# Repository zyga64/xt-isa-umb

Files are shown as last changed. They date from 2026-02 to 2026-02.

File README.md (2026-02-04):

### Simple UMB memory expansion for IBM PC (XT) and clones.

With this card, you can add 128 kB of continuous UMB memory in the D0000 - EFFFF area, or only 64 kB in the D0000 - DFFFF or E0000 - EFFFF areas. 

* Original schematic diagram was drawn by Ruud Baltissen (VCF forum thread): https://forum.vcfed.org/index.php?threads/loading-dos-high-on-a-xt.32320/
* The idea for the printed circuit board layout borrowed from Adrian Black: https://github.com/misterblack1/isa-ram-expansion
* 8 bit ISA footprint from Sergey Kiselev: https://github.com/skiselev/my_kicad_library

Diagram/PCB drawn by me in KiCad 9.0, the only minor change from Ruud's schematic is the addition of a 74LS245 buffer for the data bus (as done by Adrian and in the Lo-tech 1MB RAM Board https://www.lo-tech.co.uk/wiki/Lo-tech_1MB_RAM_Board).
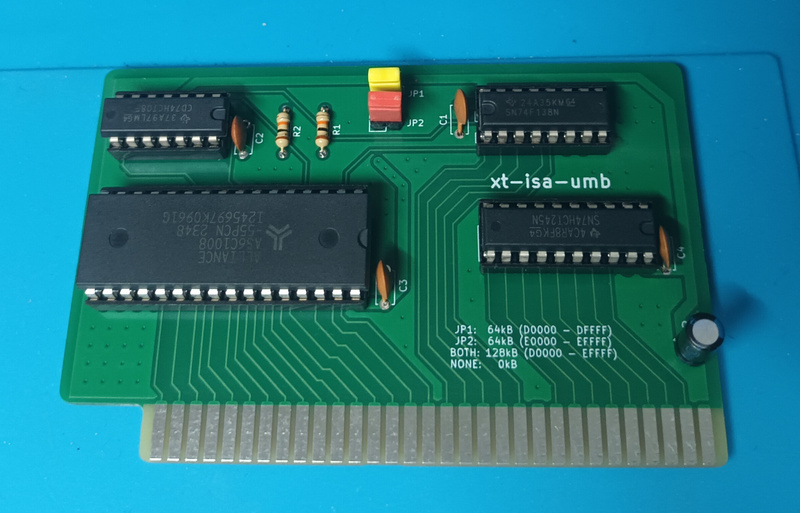
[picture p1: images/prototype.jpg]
picture of working prototype


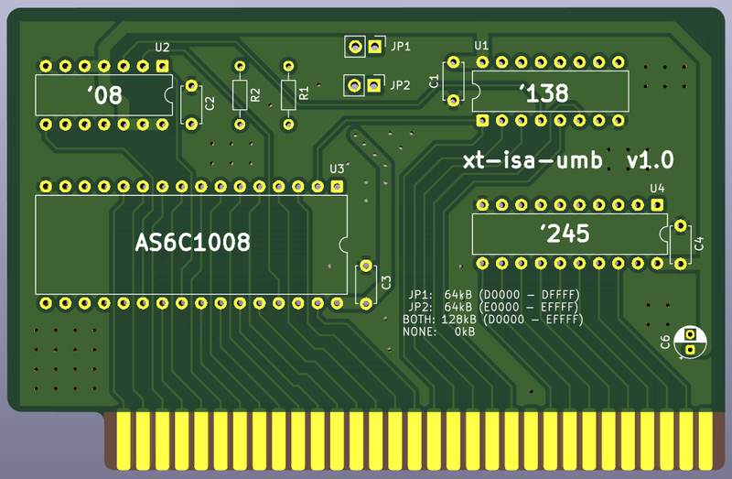
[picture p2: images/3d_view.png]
3d view of PCB


## Bill Of Materials

Reference      | Quantity    | Value                    
---------------|-------------|--------------------------
U1             | 1           | 74HCT138                  
U2             | 1           | 74HCT08                   
U3             | 1           | AS6C1008 (or another compatible 128k x 8bit SRAM)
U4             | 1           | 74HCT245                  
C6             | 1           | 47uF /16V                 
C1, C2, C3, C4 | 4           | 100nF                     
JP1, JP2       | 2           | 1x02 male through-hole pin-header 2.54mm
R1, R2         | 2           | 15k / 0.125W   (pull-up resistors - 10k will also be fine)

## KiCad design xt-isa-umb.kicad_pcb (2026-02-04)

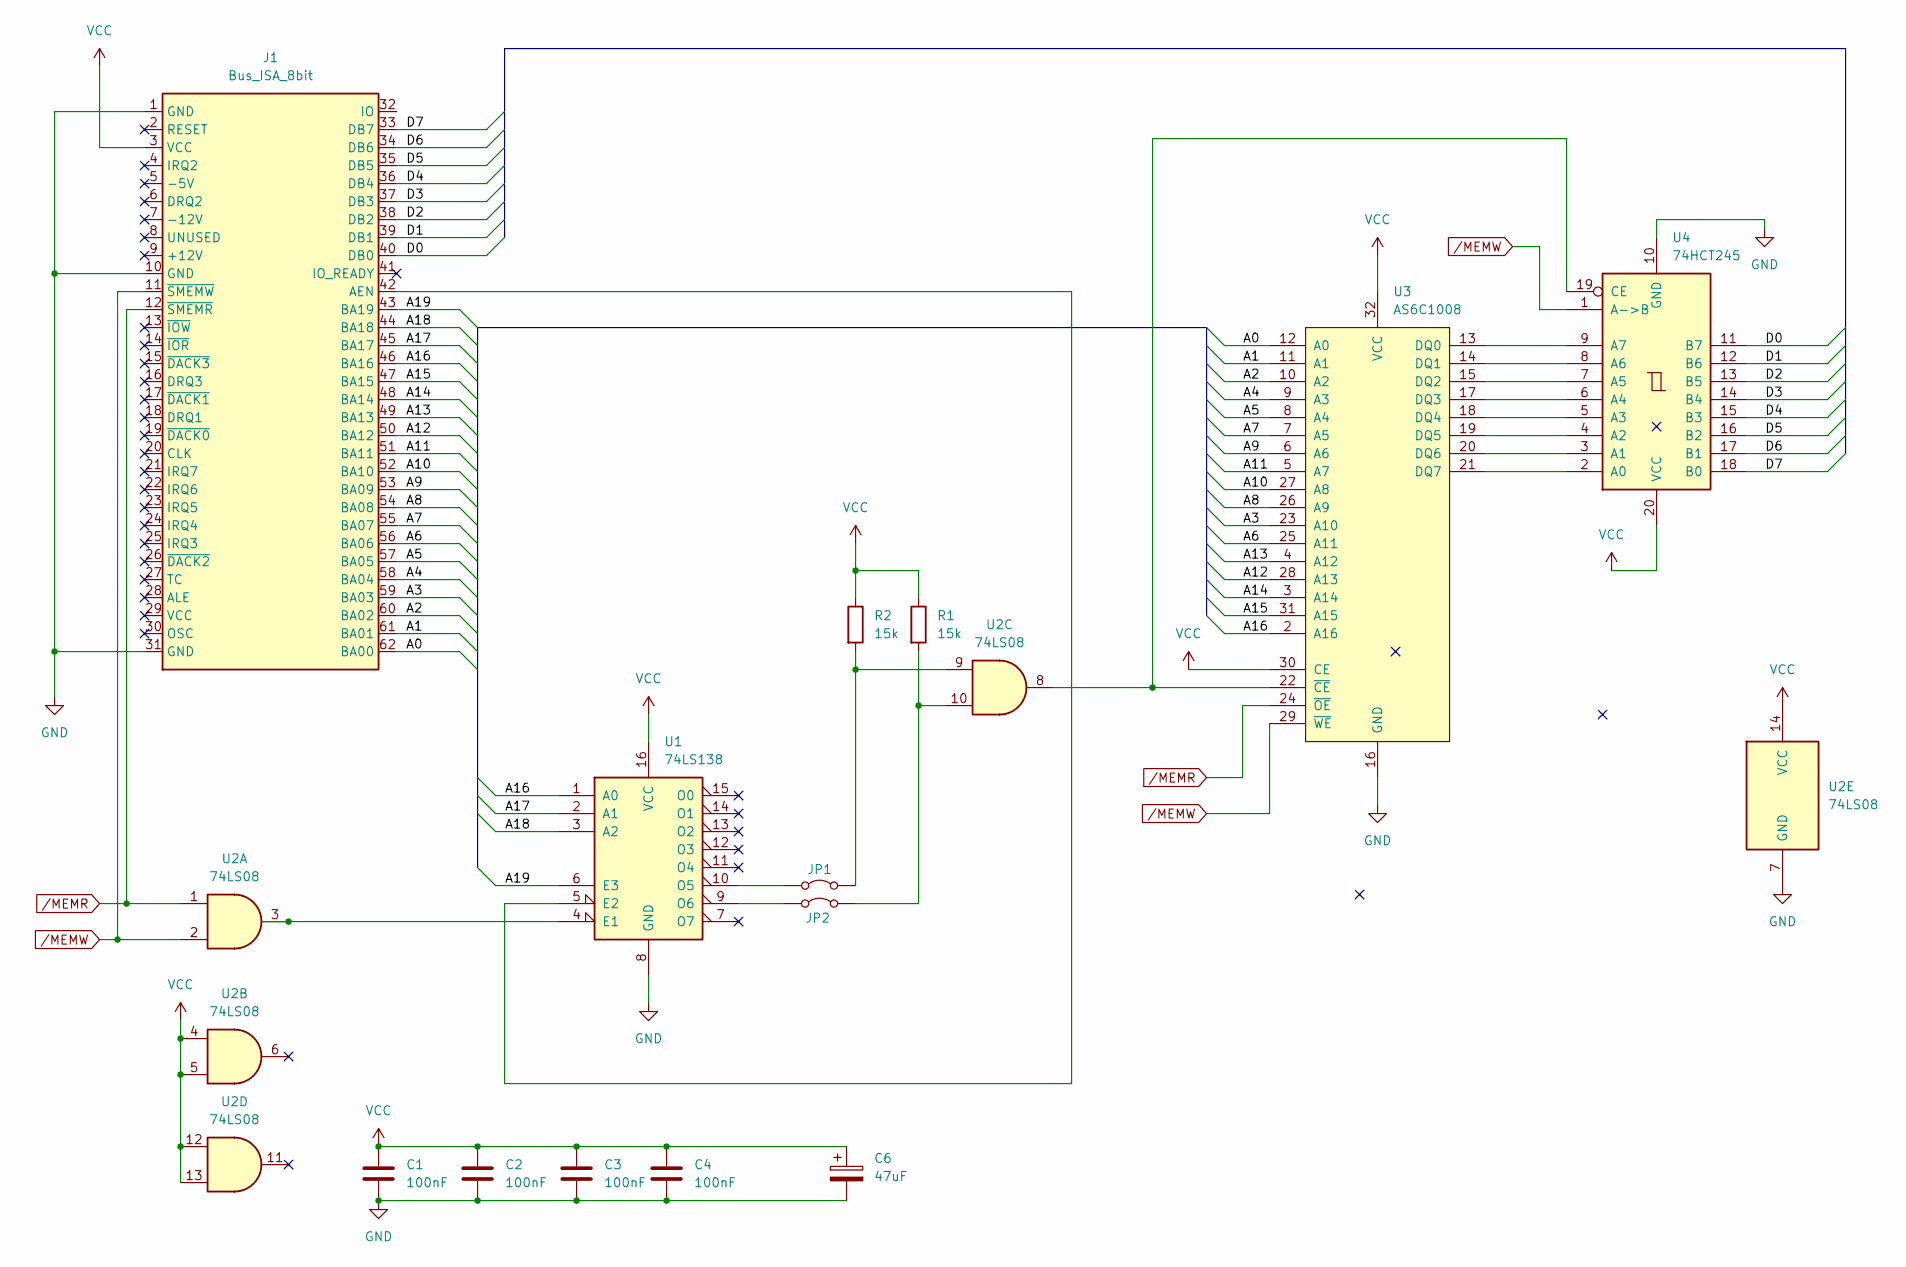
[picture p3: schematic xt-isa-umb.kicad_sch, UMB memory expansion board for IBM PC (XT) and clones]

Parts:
C1, C2, C3, C4: 100nF; C_Disc_D4.7mm_W2.5mm_P5.00mm
C6: 47uF; CP_Radial_D4.0mm_P2.00mm
J1: Bus_ISA_8bit; Conn_Edge_PCB_ISA8
JP1, JP2: Jumper_2_Bridged; PinHeader_1x02_P2.54mm_Vertical
R1, R2: 15k; R_Axial_DIN0204_L3.6mm_D1.6mm_P7.62mm_Horizontal
U1: 74LS138; DIP-16_W7.62mm
U2: 74LS08; DIP-14_W7.62mm
U3: AS6C1008; DIP-32_W15.24mm
U4: 74HCT245; DIP-20_W7.62mm

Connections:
/A0: J1.62 (BA00), U3.12 (A0)
/A1: J1.61 (BA01), U3.11 (A1)
/A2: J1.60 (BA02), U3.10 (A2)
/A3: J1.59 (BA03), U3.23 (A10)
/A4: J1.58 (BA04), U3.9 (A3)
/A5: J1.57 (BA05), U3.8 (A4)
/A6: J1.56 (BA06), U3.25 (A11)
/A7: J1.55 (BA07), U3.7 (A5)
/A8: J1.54 (BA08), U3.26 (A9)
/A9: J1.53 (BA09), U3.6 (A6)
/A10: J1.52 (BA10), U3.27 (A8)
/A11: J1.51 (BA11), U3.5 (A7)
/A12: J1.50 (BA12), U3.28 (A13)
/A13: J1.49 (BA13), U3.4 (A12)
/A14: J1.48 (BA14), U3.3 (A14)
/A15: J1.47 (BA15), U3.31 (A15)
/A16: J1.46 (BA16), U1.1 (A0), U3.2 (A16)
/A17: J1.45 (BA17), U1.2 (A1)
/A18: J1.44 (BA18), U1.3 (A2)
/A19: J1.43 (BA19), U1.6 (E3)
/D0: J1.40 (DB0), U4.11 (B7)
/D1: J1.39 (DB1), U4.12 (B6)
/D2: J1.38 (DB2), U4.13 (B5)
/D3: J1.37 (DB3), U4.14 (B4)
/D4: J1.36 (DB4), U4.15 (B3)
/D5: J1.35 (DB5), U4.16 (B2)
/D6: J1.34 (DB6), U4.17 (B1)
/D7: J1.33 (DB7), U4.18 (B0)
GND: C1.2, C2.2, C3.2, C4.2, C6.2, J1.1 (GND), J1.10 (GND), J1.31 (GND), U1.8 (GND), U2.7 (GND), U3.16 (GND), U4.10 (GND)
unnamed: J1.42 (AEN), U1.5 (E2)
unnamed: JP1.1 (A), U1.10 (O5)
unnamed: JP1.2 (B), R2.2, U2.9
unnamed: JP2.1 (A), U1.9 (O6)
unnamed: JP2.2 (B), R1.2, U2.10
unnamed: U1.4 (E1), U2.3
unnamed: U3.13 (DQ0), U4.9 (A7)
unnamed: U3.14 (DQ1), U4.8 (A6)
unnamed: U3.15 (DQ2), U4.7 (A5)
unnamed: U3.17 (DQ3), U4.6 (A4)
unnamed: U3.18 (DQ4), U4.5 (A3)
unnamed: U3.19 (DQ5), U4.4 (A2)
unnamed: U3.20 (DQ6), U4.3 (A1)
unnamed: U3.21 (DQ7), U4.2 (A0)
unnamed: U2.8, U3.22 (~CE), U4.19 (CE)
VCC: C1.1, C2.1, C3.1, C4.1, C6.1, J1.3 (VCC), R1.1, R2.1, U1.16 (VCC), U2.4, U2.5, U2.12, U2.13, U2.14 (VCC), U3.30 (CE), U3.32 (VCC), U4.20 (VCC)
/MEMR: J1.12 (~SMEMR), U2.1, U3.24 (~OE)
/MEMW: J1.11 (~SMEMW), U2.2, U3.29 (~WE), U4.1 (A->B)

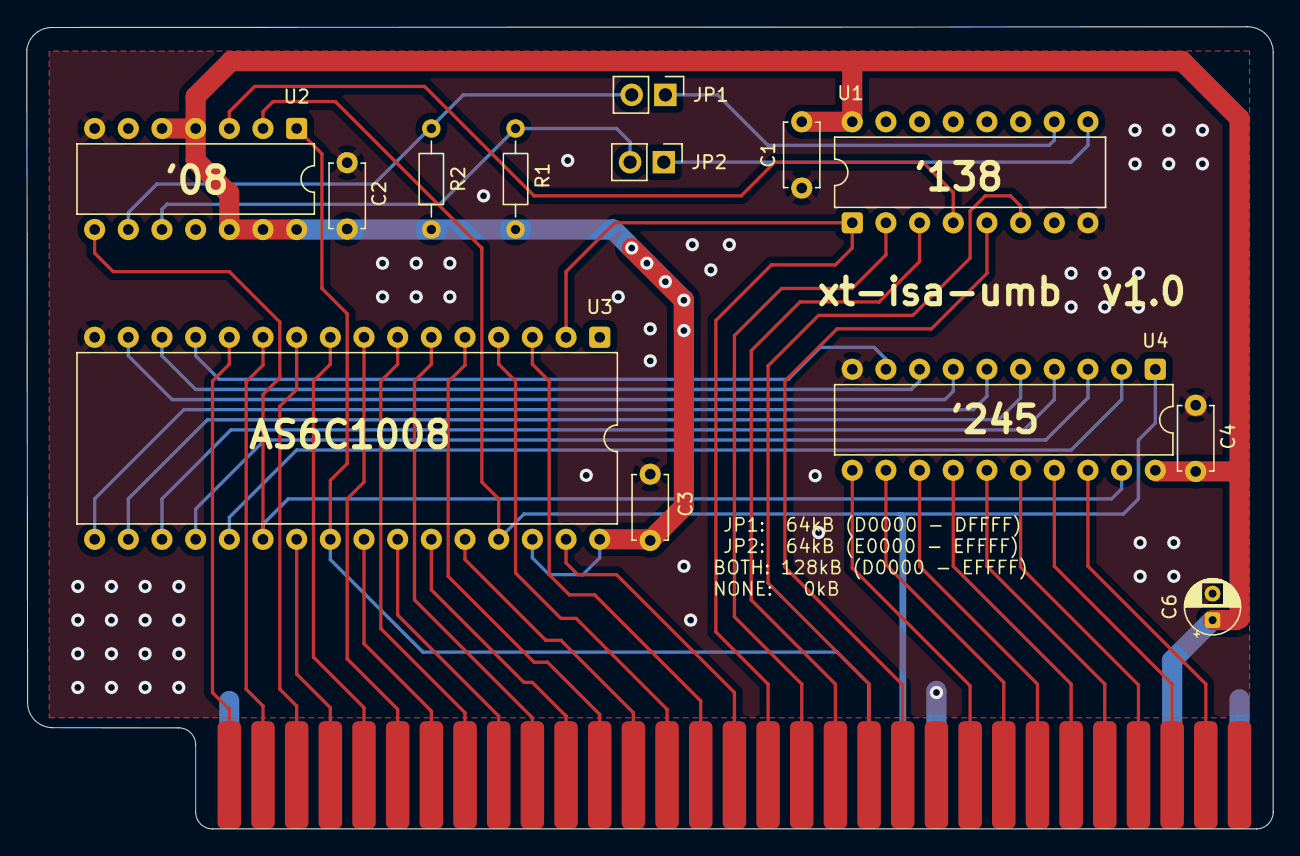
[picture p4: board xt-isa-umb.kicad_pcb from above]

Board: 2 copper layers, 94.0 x 60.5 mm, 14 parts (0 on the bottom side), 47 nets.

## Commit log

2026-01-03 added 3D view of PCB
2026-01-04 Modify capacitors and VCC/GND track placement
    [xt-isa-umb.kicad_pcb]
2026-01-04 Further VCC/GND tracks modification
    [xt-isa-umb.kicad_pcb]
2026-01-21 Add GND fill zone.
    [xt-isa-umb.kicad_pcb, xt-isa-umb.kicad_sch]
2026-01-22 Add top GND fill zone
    [xt-isa-umb.kicad_pcb]
2026-01-22 Add gerber files
    [xt-isa-umb-B_Cu.gbl, xt-isa-umb-B_Mask.gbs, xt-isa-umb-B_Paste.gbp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]
2026-02-04 Modify components designation, add thermal reliefs, change C6 orientation
    [xt-isa-umb.kicad_pcb]
2026-02-04 Revise README with new images and BOM
    Updated images and added Bill Of Materials section.
2026-02-04 Update gerbers
    [xt-isa-umb-B_Cu.gbl, xt-isa-umb-B_Mask.gbs, xt-isa-umb-B_Paste.gbp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]
